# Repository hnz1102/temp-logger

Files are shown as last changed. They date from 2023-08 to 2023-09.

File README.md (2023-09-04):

<div align="center">
  <h1><code>Temperature Logger for K-Type Thermocouple</code></h1>
  <p>
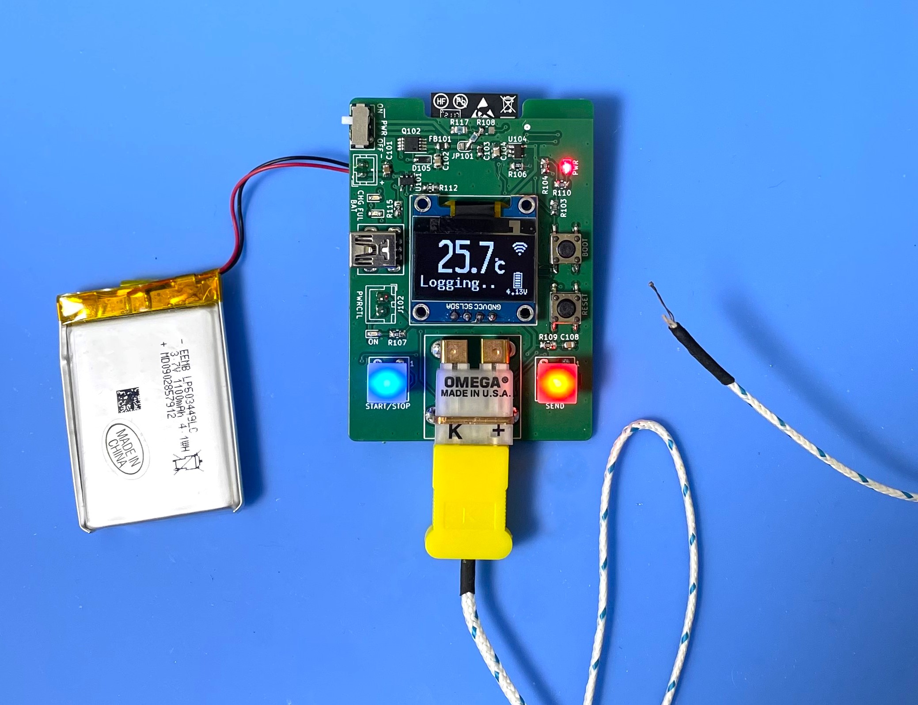
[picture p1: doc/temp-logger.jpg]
    
  </p>
</div>

# TempLogger - Temperature Logger for K-Type Thermocouple

This board provides a logging function that gets data on temperature from a K-type thermocouple.

# Feature

**Microcontroller on board** - No need for a PC when you are measuring a temperature.

**Transfer Temperature data via WiFi** - This Logger can transfer temperature data to Linux PC via WiFi network and you can see the dashboard graph in influxDB.

**Battery Powered** - Using LiPo battery. It can run for 48 hours.

# How to use the TempLogger
Put on the thermocouple where you want to measure the temperature.  

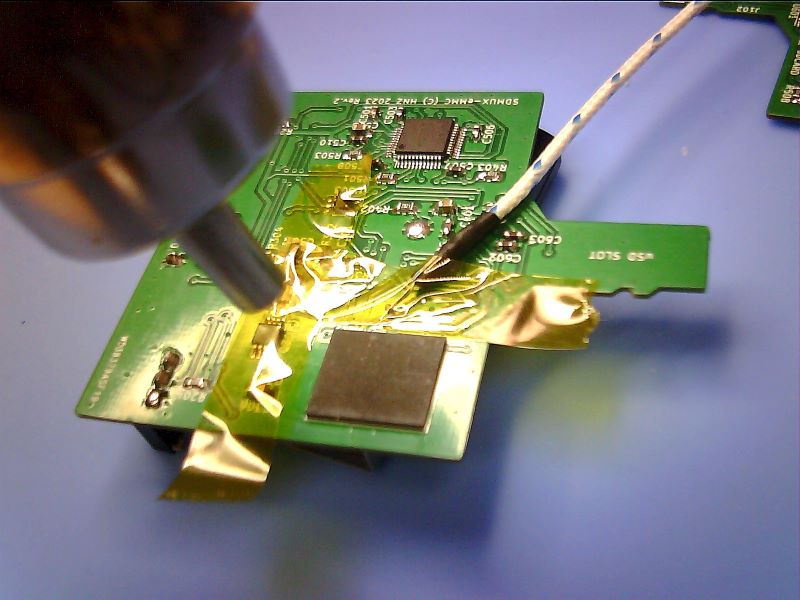
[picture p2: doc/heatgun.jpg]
termocuple


Push the START/STOP button, then TempLogger starts to log the temperature. And if you want to send data on temperature, push the SEND button. During the measurement, TempLogger can send the data to a PC. 

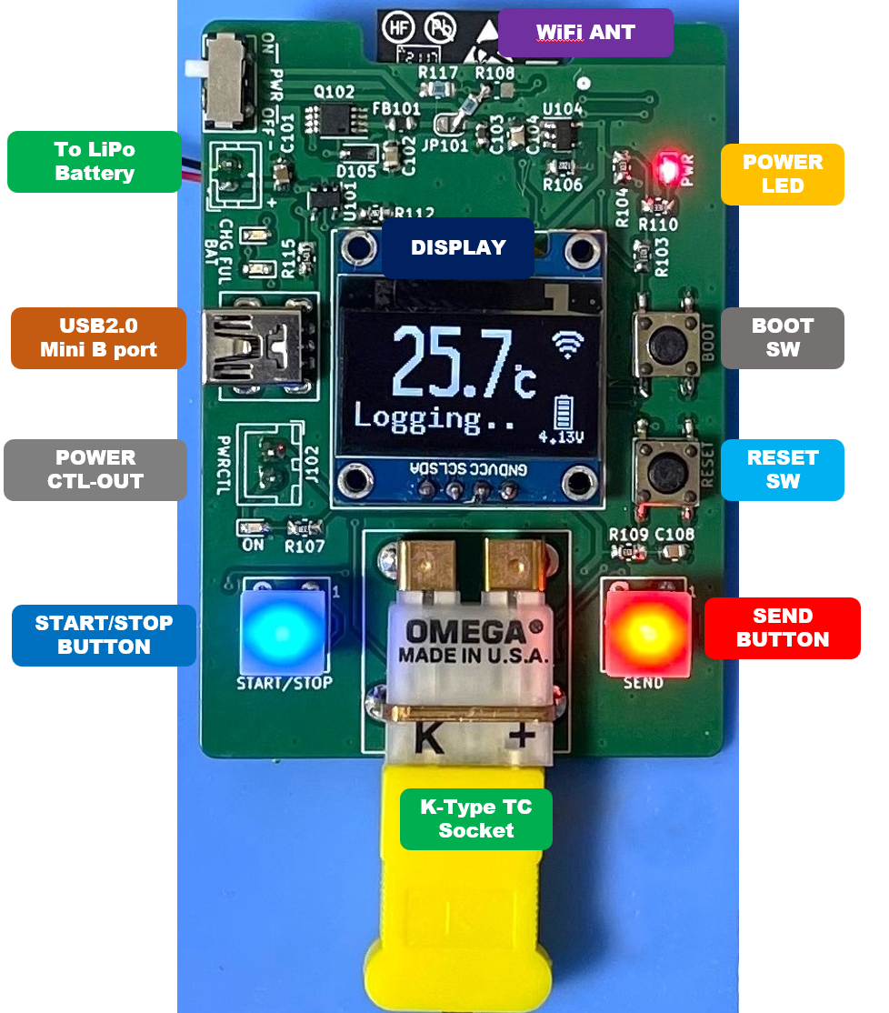
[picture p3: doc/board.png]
board


A display can show you the current temperature, battery voltage, and WiFi connection status.

If WiFi could not connect to WiFi Access Point, the WiFi mark won't be shown on the display.

You can see the realtime data using Dashboard by [InfluxDB](https://www.influxdata.com/influxdb/).

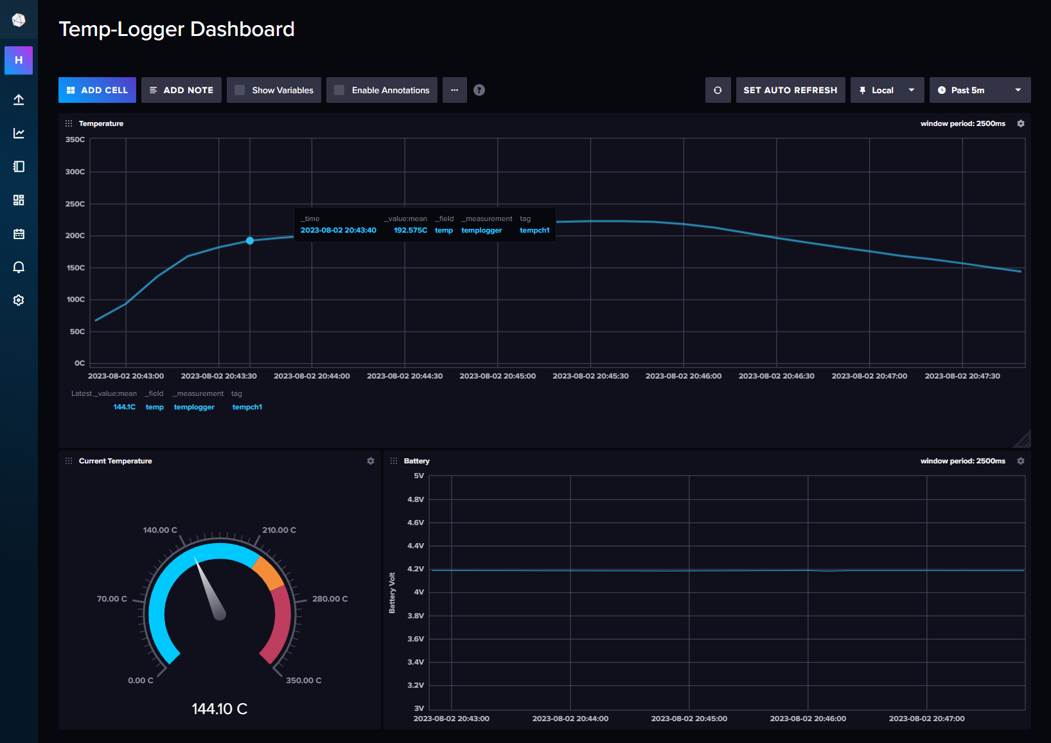
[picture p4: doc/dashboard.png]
dashboard


After the measure, to stop logging, push the START/STOP button again.

To charge a battery, just connect to a USB mini-B port from the bus-powered USB port. During the charge, the CHG LED is RED ON. After the charging is full, the FUL LED is GREEN ON. And the charging will be stopped automatically. But, 

DO NOT CONTINUE THE CHARGE IF THE BATTERY IS FULL FOR A LONG TIME. 

# Case

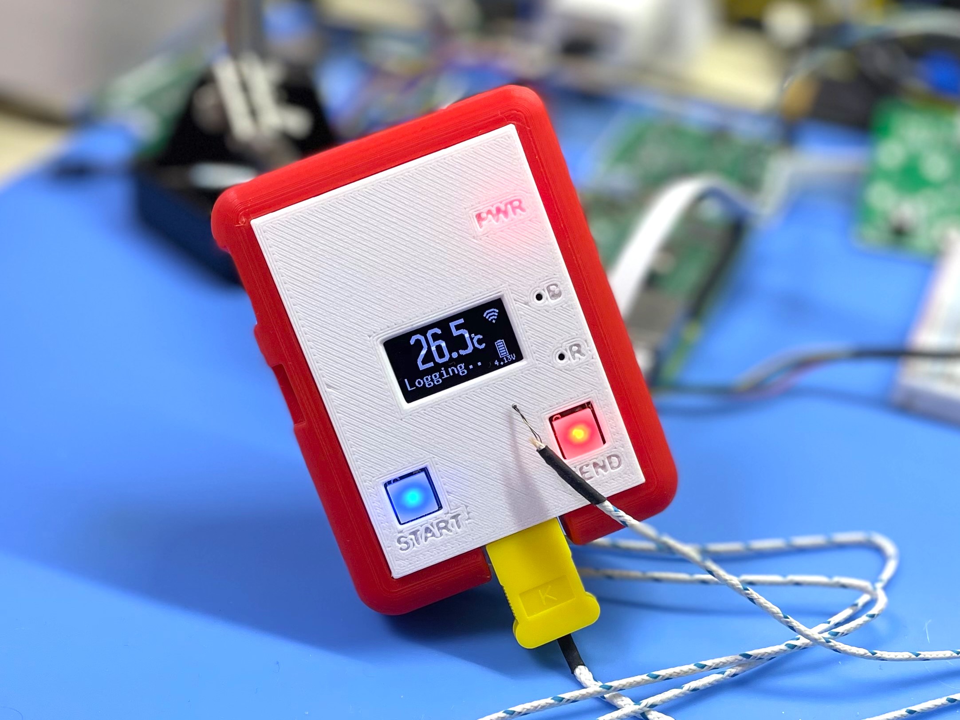
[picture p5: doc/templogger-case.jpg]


There are data for 3D printer in `hardware/*.stl`.

# How to build code

Using Ubuntu 22.04.02 LTS

1. Install Rust Compiler
```bash
$ sudo apt -y install git python3 python3-pip gcc build-essential curl pkg-config libudev-dev libtinfo5 clang libclang-dev llvm-dev udev
$ curl --proto '=https' --tlsv1.2 -sSf https://sh.rustup.rs | sh
select No.1
$ source "$HOME/.cargo/env"
```

2. Install toolchain for ESP32-C3
```bash
$ cargo install ldproxy
$ cargo install espup
$ rustup toolchain install nightly --component rust-src
$ rustup target add riscv32imc-unknown-none-elf
$ cargo install cargo-espflash
```

3. Add UDEV rules
```bash
$ sudo sh -c 'echo "SUBSYSTEMS==\"usb\", ATTRS{idVendor}==\"303a\", ATTRS{idProduct}==\"1001\", MODE=\"0666\"" > /etc/udev/rules.d/99-esp32.rules'
$ sudo udevadm control --reload-rules
$ sudo udevadm trigger
```

4. Download Temp-Logger code
```bash
$ git clone https://github.com/hnz1102/temp-logger.git
$ cd temp-logger/src/temp-logger
``` 
5. Setting WiFi SSID, Password, and InfluxDB server IP address.
```bash
src\temp-logger\cfg.toml

[templogger]
wifi_ssid = "<your-AP-ssid>"     # Set your AP ssid.
wifi_psk = "<your-AP-Password>"  # Set password for ssid
http_server = "<PC address>:3000" # Set IP address and port. port should be 3000.
```

6. Connecting the board and Set device and set toolchain.
```bash
Connecting the Temp-Logger by USB to this build code PC. Then, 
$ cargo espflash board-info
select /dev/ttyACM0
Chip type:         esp32c3 (revision v0.4)
Crystal frequency: 40MHz
Flash size:        4MB
Features:          WiFi, BLE
MAC address:       xx:xx:xx:xx:xx:xx

$ rustup component add rust-src --toolchain nightly-2023-06-10-x86_64-unknown-linux-gnu
```

7. Build code and writing flash
```bash
$ cargo espflash flash --release --monitor
App/part. size:    950,864/3,145,728 bytes, 30.23%
[00:00:00] [========================================]      12/12      0x0                                                                       
[00:00:00] [========================================]       1/1       0x8000                                                                    
[00:00:11] [========================================]     535/535     0x10000                                                                   [2023-08-03T13:05:12Z INFO ] Flashing has completed!

And automaticaly boot!
```

# How to Install the influxDB and Agent

1. Download [influxDB](https://docs.influxdata.com/influxdb/v2.7/install/?t=Linux) and Install.
```bash
$ wget https://dl.influxdata.com/influxdb/releases/influxdb2-2.7.0-amd64.deb
$ sudo dpkg -i influxdb2-2.7.0-amd64.deb
$ sudo service influxdb start
```

2. Configure the influxDB

```
Connect to the 'http://<influxDB installed PC Address>:8086'
```

Click `GET STARTED` and set `Username`, `Password`, `Initial Organization Name`, and `Initial Bucket Name`
|Term|Value|
|---|---|
|Username|Set login username as influxDB administrator web console|
|Password|Set login password as influxDB administrator web console|
|Initial Organization Name| Organization Name ex. ORG|
|Initail Bucket Name| LOGGER |

After set them, click `CONTINUE`.

3. Copy the operator API token.

You can see the operator API token on the browser. YOU WON'T BE ABLE TO SEE IT AGAIN!

After copy the token, click `CONFIGURE LATER`.

4. Import the Dashboard Template.

Click the `Dashboard` icon, and select `Import Dashboard` from the `CREATE DASHBOARD` menu.

Drop the `src/server/temp-logger_dashboard.json` file to `Drop a file here`, then click `IMPORT JSON AS DASHBOARD`.

You can see the `Temp-Logger Dashboard` pannel on the Dashboards page.

Click this panel, and You can see the Temp-Logger Dashboard.

If you want to customize the dashboard design, click configure mark. You can change the graph design.

5. Install the Agent.

Temp-Logger can't directly send data to influxDB API since ESP32-C3 has not TLS software stack. This agent program is responsible for changing HTTP communication from Temp-Logger to HTTPS communication and passing data to the InfluxDB API. This agent is purpose only for a local network because it has no security.

Before install you have to change parameters in main.js.

src/server/main.js
```javascript
const token = "<influxDB API Access Token>"
const url = 'http://<influxDB installed IP address>:8086'
let org = `<YOUR ORGANIZATION NAME: it has to be same the Initial Organization Name>`
let bucket = `LOGGER`
```

Install the agent program.

```bash
$ cd src/server/
$ ./install.sh
```
If it is `Active: active`` as shown below, it has started normally.
```
● influxdb-agent.service - InfluxDB Agent
     Loaded: loaded (/lib/systemd/system/influxdb-agent.service; enabled; vendor preset: enabled)
     Active: active (running) since Sat 2023-08-05 02:24:18 UTC; 15ms ago
```

6. Start Temp-Logger Logging and Send Data.

Push the START/STOP button, and push SEND button. Logging data will be sent to the influxDB. You can see the data on the dashboard.

# Add Battery Monitor

A small modification was made to monitor the battery voltage.

I already fixed new PCB gerber data.

## LICENSE
This source code is licensed under MIT. Other Hardware Schematic documents are licensed under CC-BY-SA V4.0.

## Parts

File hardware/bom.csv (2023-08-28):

Reference | Value | Footprint | akizuki | digikey | storeURL | Qty
C101 | 4.7uF | Capacitor_SMD:C_0805_2012Metric_Pad1.18x1.45mm_HandSolder |  | 311-1455-1-ND | https://www.digikey.com/en/products/detail/yageo/CC0603KRX5R6BB475/2833620 | 1
C102, C108 | 1uF | Capacitor_SMD:C_0805_2012Metric |  | 13-CC0603KPX7R7BB105CT-ND | https://www.digikey.com/en/products/detail/yageo/CC0603KPX7R7BB105/11491211 | 2
C103, C106, C111 | 0.1uF | Capacitor_SMD:C_0603_1608Metric_Pad1.08x0.95mm_HandSolder |  | 311-1824-1-ND | https://www.digikey.com/en/products/detail/yageo/CC0603MRX7R7BB104/5195231 | 3
C104, C107 | 10uF | Capacitor_SMD:C_0805_2012Metric_Pad1.18x1.45mm_HandSolder |  | 311-3494-1-ND | https://www.digikey.com/en/products/detail/yageo/CC0603MRX5R8BB106/7164378 | 2
C105 | 0.1uF | Capacitor_SMD:C_0603_1608Metric |  | 311-1824-1-ND | https://www.digikey.com/en/products/detail/yageo/CC0603MRX7R7BB104/5195231 | 1
C109, C110 | 16pF | Capacitor_SMD:C_0603_1608Metric_Pad1.08x0.95mm_HandSolder |  | 311-1751-1-ND | https://www.digikey.com/en/products/detail/yageo/CC0603JRNPO0BN160/5195160 | 2
D101-D103 | LED RED SML-E12V8WT86 | tbctl:LED_0603_1608Metric_Pad1.05x0.95mm_HandSolder |  | 511-1587-1-ND | https://www.digikey.com/en/products/detail/rohm-semiconductor/SML-E12V8WT86/1641806 | 3
D104 | LED GREEN SML-E12P8WT86 | tbctl:LED_0603_1608Metric_Pad1.05x0.95mm_HandSolder |  | 511-1585-1-ND | https://www.digikey.com/en/products/detail/rohm-semiconductor/SML-E12P8WT86/1641804 | 1
D105 | NSR0340HT1G | Diode_SMD:D_SOD-323_HandSoldering |  | NSR0340HT1GOSCT-ND | https://www.digikey.com/en/products/detail/onsemi/NSR0340HT1G/1981491 | 1
FB101 | BK2125HS601-T | tbctl:L_0603_1608Metric_Pad1.05x0.95mm_HandSolder |  | 240-2399-1-ND | https://www.digikey.com/en/products/detail/laird-signal-integrity-products/HZ0805E601R-10/806759 | 1
J101 | Conn_K_TERM_XH_2P | tbctl:PCC-SMP_D | P-14972 | 1568-1306-ND | https://www.digikey.com/en/products/detail/sparkfun-electronics/PRT-13612/5762456 | 1
J102 | Conn_01x02 | Connector_JST:JST_XH_B2B-XH-A_1x02_P2.50mm_Vertical | C-12247 | 455-2247-ND | https://www.digikey.com/en/products/detail/jst-sales-america-inc/B2B-XH-A-LF-SN/1651045 | 1
J103 | USB_B_Mini | tbctl:usb mini B connector c2235 dim 2 | C-02235 |  | https://akizukidenshi.com/catalog/g/gC-02235/ | 1
J104 | LiPo BATTERY Socket | Connector_JST:JST_PH_B2B-PH-K_1x02_P2.00mm_Vertical | C-12802 | 455-1704-ND | https://www.digikey.com/en/products/detail/jst-sales-america-inc/B2B-PH-K-S/926611 | 1
JP101 | SolderJumper_2_Open | Jumper:SolderJumper-2_P1.3mm_Open_RoundedPad1.0x1.5mm |  |  |  | 1
Q101 | 2N7002K | Package_TO_SOT_SMD:SOT-23 |  | 2N7002K-7DICT-ND | https://www.digikey.com/en/products/detail/diodes-incorporated/2N7002K-7/1934378 | 1
Q102 | IRF7606TRPBF | Package_SO:MSOP-8_3x3mm_P0.65mm |  | IRF7606TRPBFCT-ND | https://www.digikey.com/en/products/detail/infineon-technologies/IRF7606TRPBF/856652 | 1
R101, R102, R107, R110, R113, R114 | 330 | tbctl:R_0805_2012Metric_Pad1.20x1.40mm_HandSolder |  | 311-330GRCT-ND | https://www.digikey.com/en/products/detail/yageo/RC0603JR-07330RL/726769 | 6
R103, R104, R109, R111, R118 | 10K | tbctl:R_0805_2012Metric_Pad1.20x1.40mm_HandSolder |  | 13-RC0603JR-1010KLCT-ND | https://www.digikey.com/en/products/detail/yageo/RC0603JR-1010KL/13694233 | 5
R105, R108, R117 | 20K 1% | tbctl:R_0805_2012Metric_Pad1.20x1.40mm_HandSolder |  | 13-RC0603FR-1320KLCT-ND | https://www.digikey.com/en/products/detail/yageo/RC0603FR-1320KL/13694225 | 3
R106 | 12K 1% | tbctl:R_0805_2012Metric_Pad1.20x1.40mm_HandSolder |  | 311-12.0KHRCT-ND | https://www.digikey.com/en/products/detail/yageo/RC0603FR-0712KL/726913 | 1
R112 | 2K | tbctl:R_0805_2012Metric_Pad1.20x1.40mm_HandSolder |  | 311-2.0KGRCT-ND | https://www.digikey.com/en/products/detail/yageo/RC0603JR-072KL/726726 | 1
R115 | 100K | tbctl:R_0805_2012Metric_Pad1.20x1.40mm_HandSolder |  | 311-100KGRCT-ND | https://www.digikey.com/en/products/detail/yageo/RC0603JR-07100KL/726698 | 1
SW101 | SW_Push_LED | tbctl:LS601-CU_CAP |  |  | https://akizukidenshi.com/catalog/g/gP-13871/ | 1
SW102 | SW_Push_LED | tbctl:LS601-CU_CAP |  |  | https://akizukidenshi.com/catalog/g/gP-13870/ | 1
SW103 | BOOT TS-06104 | tbctl:TS-06104 | P-15969 |  | https://akizukidenshi.com/catalog/g/gP-15969/ | 1
SW104 | RESET TS-06104 | tbctl:TS-06104 | P-15969 |  | https://akizukidenshi.com/catalog/g/gP-15969/ | 1
SW105 | SLIDE_SW IS-1245T-G | tbctl:SLIDE_SW_IS1235-G | P-15368 |  | https://akizukidenshi.com/catalog/g/gP-15368/ | 1
U101 | MCP73831-2-OT | Package_TO_SOT_SMD:SOT-23-5 | I-13288 | MCP73831T-2ACI/OTCT-ND | https://www.digikey.com/en/products/detail/microchip-technology/MCP73831T-2ACI-OT/964301 | 1
U102 | ESP32-C3-WROOM-02-N4 | tbctl:IC18_ESP32-C3-WROOM-02-N4_EXP | M-17493 | 1965-ESP32-C3-WROOM-02-N4CT-ND | https://www.digikey.com/en/products/detail/espressif-systems/ESP32-C3-WROOM-02-N4/14553031 | 1
U103 | MAX31855KASA | Package_SO:SOIC-8_3.9x4.9mm_P1.27mm | I-14486 | MAX31855KASA+TCT-ND | https://www.digikey.com/en/products/detail/analog-devices-inc-maxim-integrated/MAX31855KASA-T/2591213 | 1
U104 | SPX3819M5-L | Package_TO_SOT_SMD:SOT-23-5 |  | 1016-1871-1-ND | https://www.digikey.com/en/products/detail/maxlinear-inc/SPX3819M5-L-TR/2472388 | 1
U105 | SSD1306_DISPLAY | tbctl:OLED I2C DISPLAY |  |  | https://www.amazon.co.jp/gp/product/B08CTZVVLS/ | 1
Y102 | 32.7680KHz | Crystal:Crystal_SMD_3215-2Pin_3.2x1.5mm |  | 2151-RT3215-32.768-12.5-TRCT-ND | https://www.digikey.com/en/products/detail/raltron-electronics/RT3215-32-768-12-5-TR/10273025 | 1

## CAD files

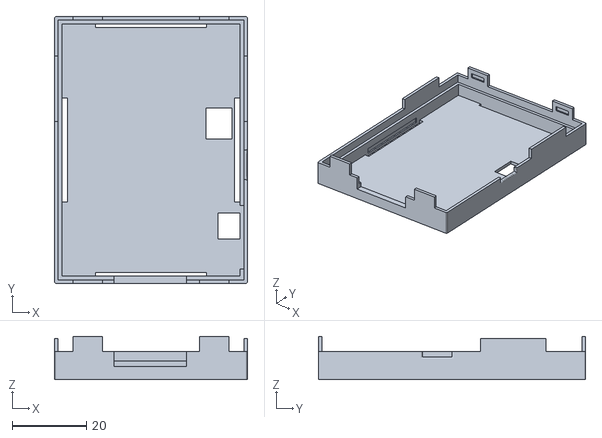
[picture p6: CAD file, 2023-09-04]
hardware/Bottom-v11.stl
52.0 x 72.0 x 11.6

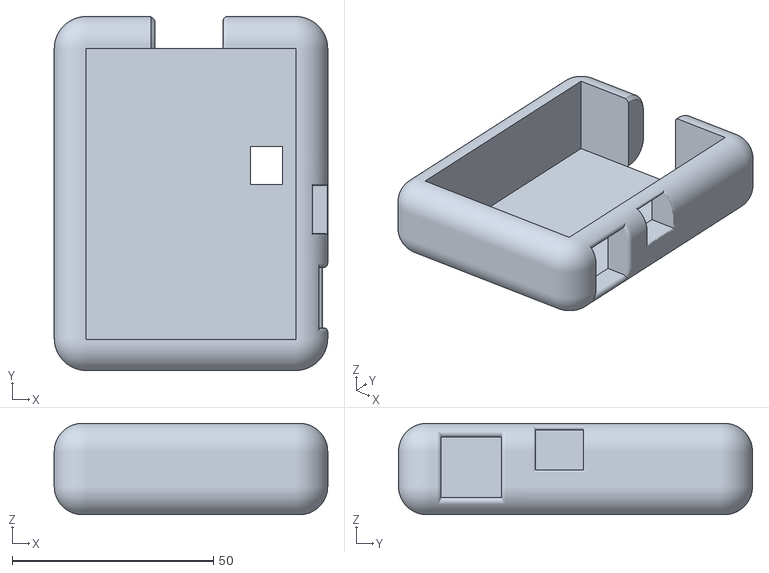
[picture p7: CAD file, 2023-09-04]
hardware/cover-v11.stl
68.0 x 88.0 x 22.7

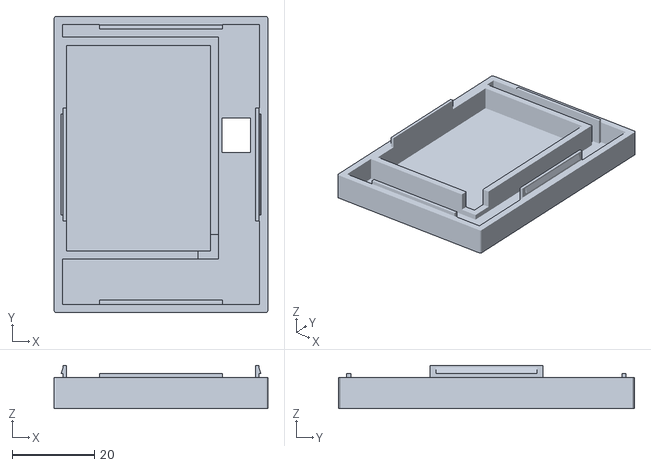
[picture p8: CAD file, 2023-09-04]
hardware/battery-v11.stl
52.0 x 72.0 x 10.5

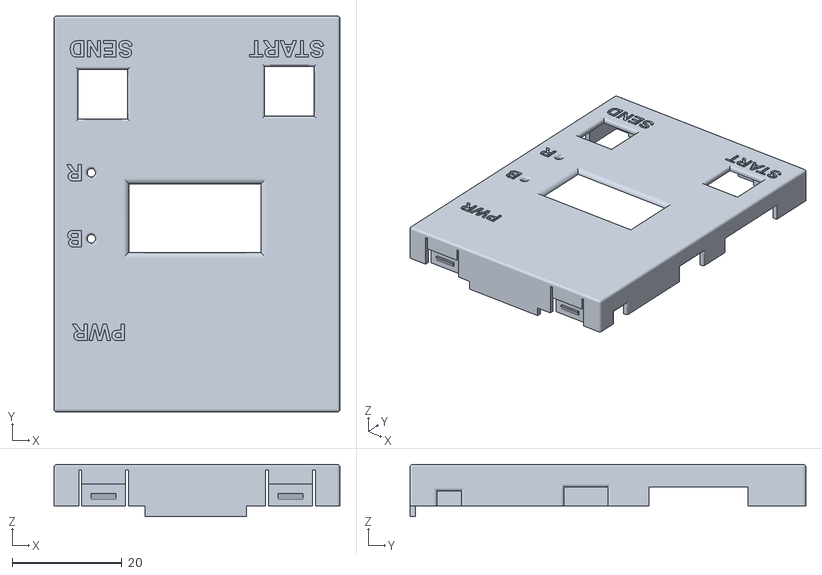
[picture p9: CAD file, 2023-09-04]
hardware/upper-v11.stl
52.0 x 72.0 x 9.50

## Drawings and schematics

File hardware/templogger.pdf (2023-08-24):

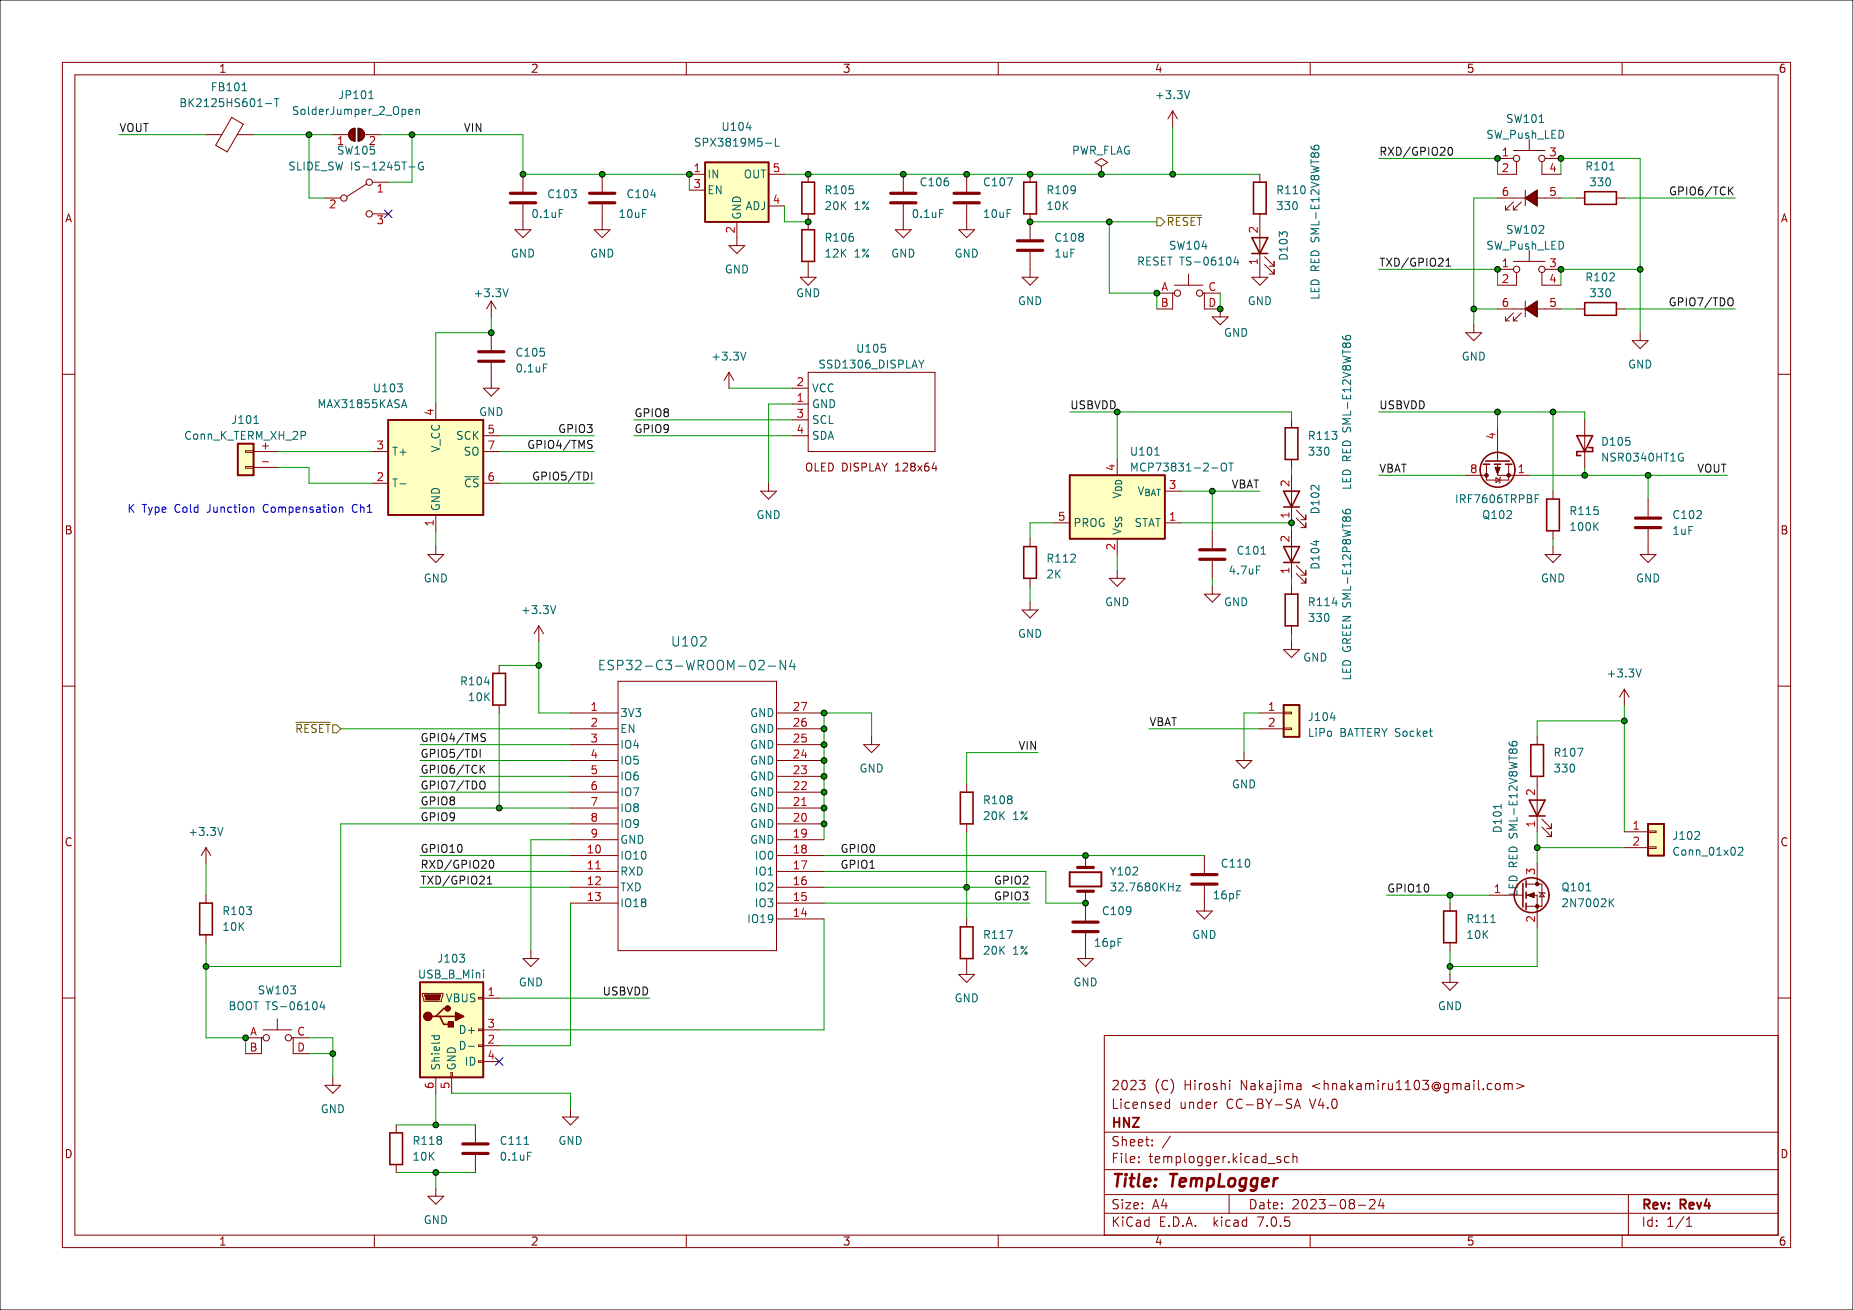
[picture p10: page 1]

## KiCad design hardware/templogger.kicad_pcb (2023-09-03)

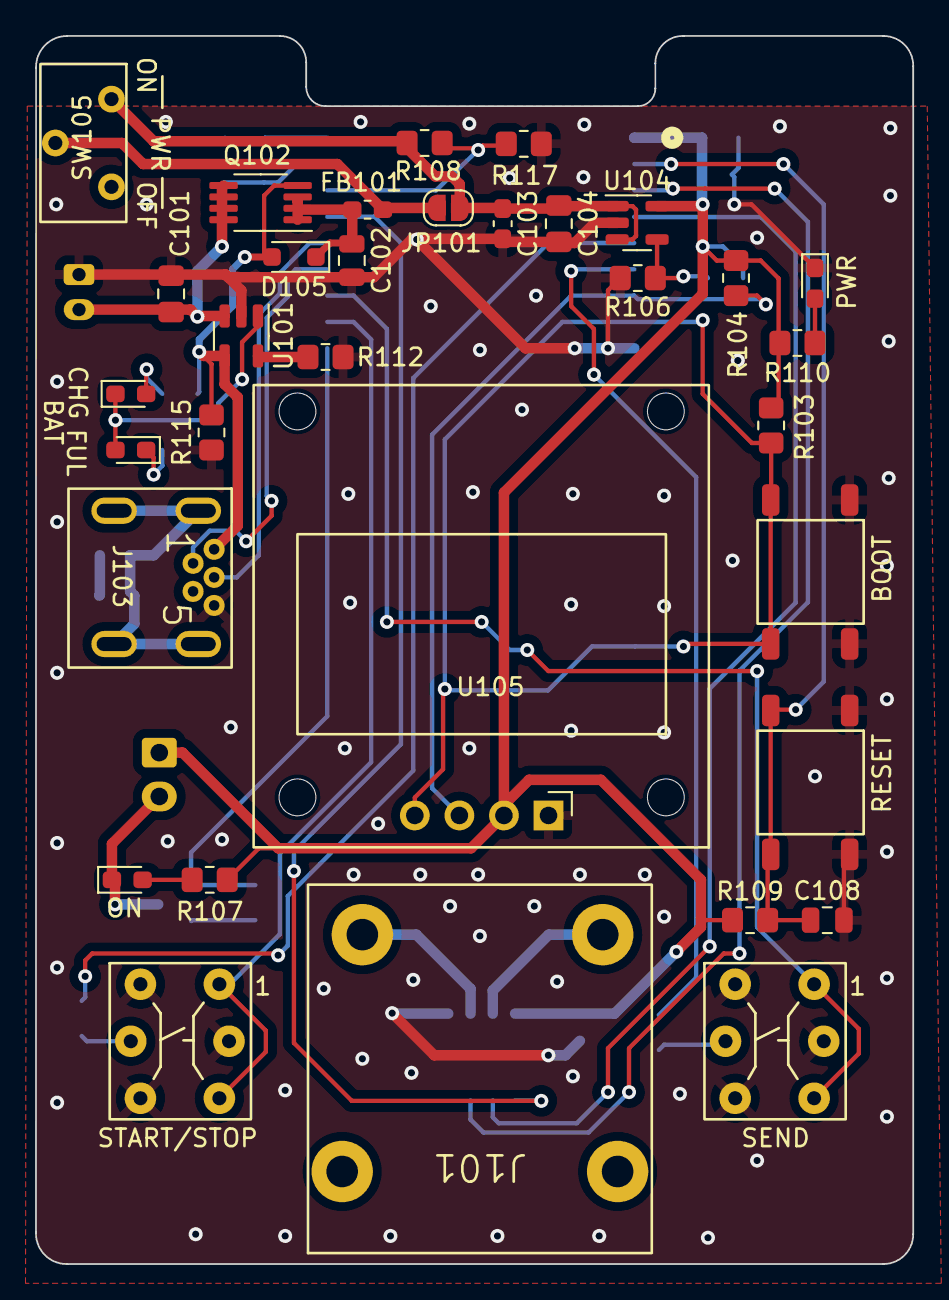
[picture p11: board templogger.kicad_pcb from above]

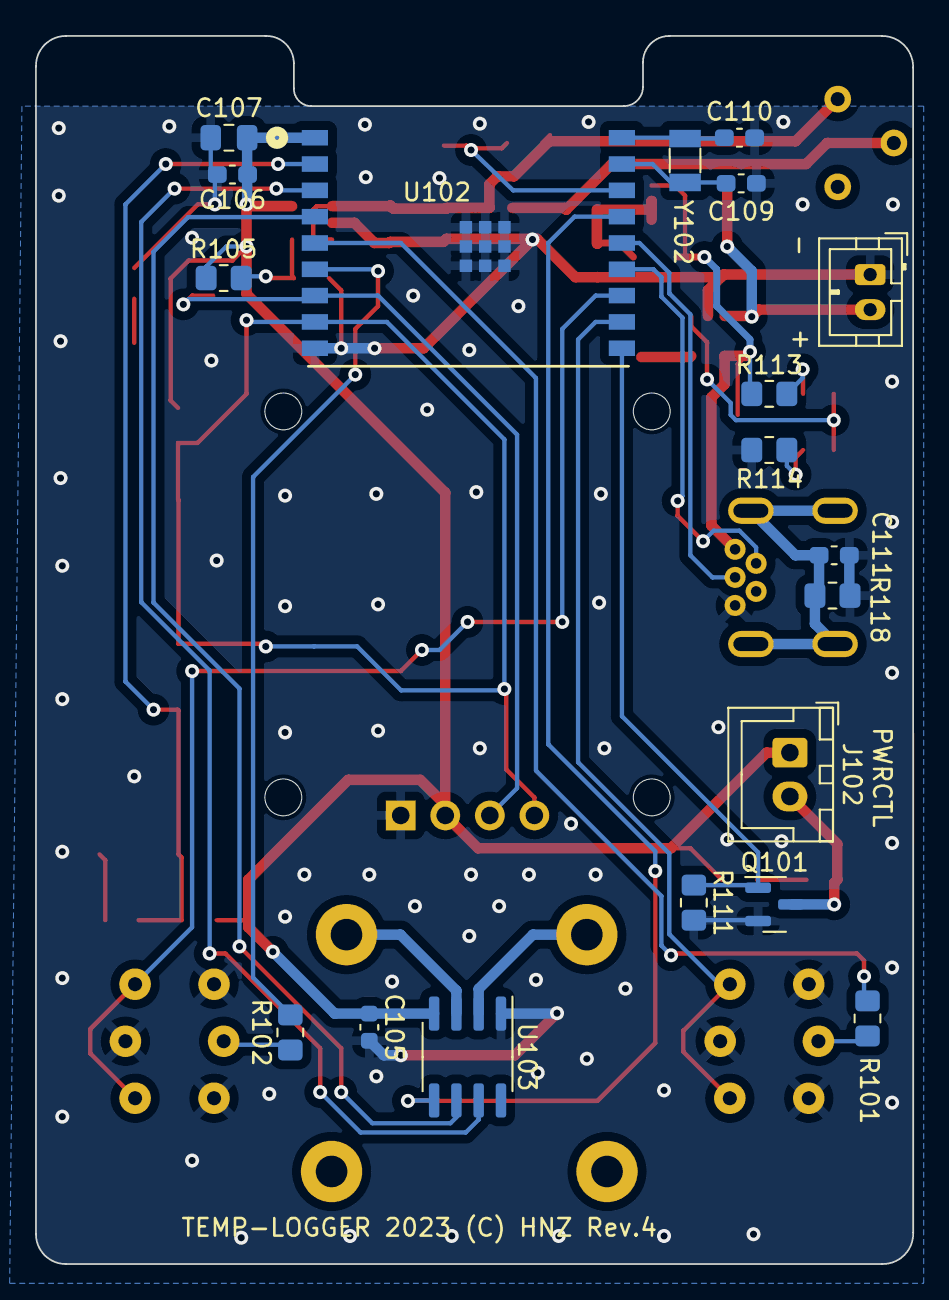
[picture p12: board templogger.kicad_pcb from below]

Board: 2 copper layers, 50.0 x 70.0 mm, 52 parts (19 on the bottom side), 36 nets.

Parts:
C101: 4.7uF; C_0805_2012Metric_Pad1.18x1.45mm_HandSolder
C102, C108: 1uF; C_0805_2012Metric
C103, C106, C111: 0.1uF; C_0603_1608Metric_Pad1.08x0.95mm_HandSolder
C104, C107: 10uF; C_0805_2012Metric_Pad1.18x1.45mm_HandSolder
C105: 0.1uF; C_0603_1608Metric
C109, C110: 16pF; C_0603_1608Metric_Pad1.08x0.95mm_HandSolder
D101, D102, D103: LED RED SML-E12V8WT86; LED_0603_1608Metric_Pad1.05x0.95mm_HandSolder
D104: LED GREEN SML-E12P8WT86; LED_0603_1608Metric_Pad1.05x0.95mm_HandSolder
D105: NSR0340HT1G; D_SOD-323_HandSoldering
FB101: BK2125HS601-T; L_0603_1608Metric_Pad1.05x0.95mm_HandSolder
J101: Conn_K_TERM_XH_2P; PCC-SMP_D
J102: Conn_01x02; JST_XH_B2B-XH-A_1x02_P2.50mm_Vertical
J103: USB_B_Mini; usb mini B connector c2235 dim 2
J104: LiPo BATTERY Socket; JST_PH_B2B-PH-K_1x02_P2.00mm_Vertical
JP101: SolderJumper_2_Open; SolderJumper-2_P1.3mm_Open_RoundedPad1.0x1.5mm
Q101: 2N7002K; SOT-23
Q102: IRF7606TRPBF; MSOP-8_3x3mm_P0.65mm
R101, R102, R107, R110, R113, R114: 330; R_0805_2012Metric_Pad1.20x1.40mm_HandSolder
R103, R104, R109, R111, R118: 10K; R_0805_2012Metric_Pad1.20x1.40mm_HandSolder
R105, R108, R117: 20K 1%; R_0805_2012Metric_Pad1.20x1.40mm_HandSolder
R106: 12K 1%; R_0805_2012Metric_Pad1.20x1.40mm_HandSolder
R112: 2K; R_0805_2012Metric_Pad1.20x1.40mm_HandSolder
R115: 100K; R_0805_2012Metric_Pad1.20x1.40mm_HandSolder
SW101, SW102: SW_Push_LED; LS601-CU_CAP
SW103: BOOT TS-06104; TS-06104
SW104: RESET TS-06104; TS-06104
SW105: SLIDE_SW IS-1245T-G; SLIDE_SW_IS1235-G
U101: MCP73831-2-OT; SOT-23-5
U102: ESP32-C3-WROOM-02-N4; IC18_ESP32-C3-WROOM-02-N4_EXP
U103: MAX31855KASA; SOIC-8_3.9x4.9mm_P1.27mm
U104: SPX3819M5-L; SOT-23-5
U105: SSD1306_DISPLAY; OLED I2C DISPLAY
Y102: 32.7680KHz; Crystal_SMD_3215-2Pin_3.2x1.5mm

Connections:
+3.3V: C105.1, C106.1, C107.1, J102.1, R103.1, R104.1, R105.1, R107.1, R109.1, R110.1, U102.1 (3V3), U103.4 (V_CC), U104.5 (OUT), U105.2 (VCC)
/GPIO0: C110.1, U102.18 (IO0), Y102.2
/GPIO1: C109.1, U102.17 (IO1), Y102.1
/GPIO2: R108.2, R117.1, U102.16 (IO2)
/GPIO3: U102.15 (IO3), U103.5 (SCK)
/GPIO4/TMS: U102.3 (IO4), U103.7 (SO)
/GPIO5/TDI: U102.4 (IO5), U103.6 (~CS)
/GPIO6/TCK: R101.2, U102.5 (IO6)
/GPIO7/TDO: R102.2, U102.6 (IO7)
/GPIO8: R104.2, U102.7 (IO8), U105.3 (SCL)
/GPIO9: R103.2, SW103.A, SW103.B, U102.8 (IO9), U105.4 (SDA)
/GPIO10: Q101.1 (G), R111.1, U102.10 (IO10)
/RXD/GPIO20: SW101.1, SW101.2, U102.11 (RXD)
/TXD/GPIO21: SW102.1, SW102.2, U102.12 (TXD)
/USBVDD: D105.2 (A), J103.1 (VBUS), Q102.4 (G), R113.1, R115.1, U101.4 (V_{DD})
/VBAT: C101.1, J104.2, Q102.5 (D), Q102.6 (D), Q102.7 (D), Q102.8 (D), U101.3 (V_{BAT})
/VIN: C103.1, C104.1, JP101.2 (B), R108.1, SW105.1 (A), U104.1 (IN), U104.3 (EN)
/VOUT: C102.1, D105.1 (K), FB101.1, Q102.1 (S), Q102.2 (S), Q102.3 (S)
/~RESET: C108.1, R109.2, SW104.A, SW104.B, U102.2 (EN)
GND: C101.2, C102.2, C103.2, C104.2, C105.2, C106.2, C107.2, C108.2, C109.2, C110.2, C111.2, D103.1 (K), J103.5 (GND), J104.1, Q101.2 (S), R106.2, R111.2, R112.2, R114.2, R115.2, R117.2, R118.2, SW101.3, SW101.4, SW101.6 (K), SW102.3, SW102.4, SW102.6 (K), SW103.C, SW103.D, SW104.C, SW104.D, U101.2 (V_{SS}), U102.9 (GND), U102.19 (GND), U102.20 (GND), U102.21 (GND), U102.22 (GND), U102.23 (GND), U102.24 (GND), U102.25 (GND), U102.26 (GND), U102.27 (GND), U103.1 (GND), U104.2 (GND), U105.1 (GND)
unnamed: D101.2 (A), R107.2
unnamed: D101.1 (K), J102.2, Q101.3 (D)
unnamed: D102.2 (A), R113.2
unnamed: D102.1 (K), D104.2 (A), U101.1 (STAT)
unnamed: D103.2 (A), R110.2
unnamed: D104.1 (K), R114.1
unnamed: J103.3 (D+), U102.14 (IO19)
unnamed: J103.2 (D-), U102.13 (IO18)
unnamed: C111.1, J103.6 (Shield), R118.1
unnamed: FB101.2, JP101.1 (A), SW105.2 (B)
unnamed: R101.1, SW101.5 (A)
unnamed: R102.1, SW102.5 (A)
unnamed: R112.1, U101.5 (PROG)
unnamed: J101.+, U103.3 (T+)
unnamed: J101.-, U103.2 (T-)
unnamed: R105.2, R106.1, U104.4 (ADJ)

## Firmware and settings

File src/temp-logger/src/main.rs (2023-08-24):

use std::{thread, time::Duration};
use esp_idf_hal::{gpio::*, prelude::*, spi, i2c};
use esp_idf_hal::peripherals::Peripherals;
use esp_idf_hal::ledc::{config::TimerConfig, LedcDriver, LedcTimerDriver};
use embedded_hal::spi::MODE_0;
use log::*;
use std::time::SystemTime;
use esp_idf_hal::adc::config::Config as AdcConfig;
use esp_idf_hal::adc::AdcChannelDriver;
use esp_idf_hal::adc::AdcDriver;
use esp_idf_hal::adc::Atten11dB;

mod pushswitch;
mod displayctl;
mod templogs;
mod wifi;
mod transfer;

use pushswitch::PushSwitch;
use displayctl::{DisplayPanel, LoggingStatus, WifiStatus};
use templogs::{TempRecord, TempLog};
use transfer::Transfer;

#[toml_cfg::toml_config]
pub struct Config {
    #[default("")]
    wifi_ssid: &'static str,
    #[default("")]
    wifi_psk: &'static str,
    #[default("")]
    http_server: &'static str,
}

struct Temperature {
    _ta: f32,
    tr: f32,
    msg: String,
}

fn main() -> anyhow::Result<()> {
    esp_idf_sys::link_patches();
    esp_idf_svc::log::EspLogger::initialize_default();

    // Peripherals Initialize
    let peripherals = Peripherals::take().unwrap();
    
    // PWM
    let timer_driver = LedcTimerDriver::new(peripherals.ledc.timer0, &TimerConfig::default().frequency(50.Hz().into())).unwrap();
    let mut pwm_driver = LedcDriver::new(peripherals.ledc.channel0, timer_driver, peripherals.pins.gpio10).unwrap();
    pwm_driver.set_duty(0).expect("Set duty failure");
    // SPI Temperature
    let spi = peripherals.spi2;
    let sclk = peripherals.pins.gpio3;
    let sdi  = peripherals.pins.gpio4;
    let sdo_not_used = peripherals.pins.gpio1;
    let cs1 = peripherals.pins.gpio5;
    let spi_config = spi::SpiConfig::new().baudrate(1.MHz().into()).data_mode(MODE_0);
    let spi_driver = spi::SpiDriver::new(
        spi,
        sclk,
        sdo_not_used,
        Some(sdi),
        spi::Dma::Disabled,
    ).unwrap();
    
    let spi_shared_device = spi::SpiSharedDeviceDriver::new(spi_driver, &spi_config).unwrap();
    let mut spi1 = spi::SpiSoftCsDeviceDriver::new(&spi_shared_device, cs1, esp_idf_hal::gpio::Level::High).unwrap();

    // Display
    let i2c = peripherals.i2c0;
    let scl = peripherals.pins.gpio8;
    let sda = peripherals.pins.gpio9;
    let config = i2c::I2cConfig::new().baudrate(1.MHz().into());
    let i2c = i2c::I2cDriver::new(i2c, sda, scl, &config)?;
    let mut dp = DisplayPanel::new();
    dp.start(i2c);

    // PushSW
    let startstop_pin   = peripherals.pins.gpio20;
    let send_pin        = peripherals.pins.gpio21;
    let startstop_sig   = Box::new(PinDriver::input(startstop_pin)?);
    let send_sig        = Box::new(PinDriver::input(send_pin)?);
    let mut psw         = PushSwitch::new();
    psw.start(startstop_sig, send_sig);
    let mut startstop_led   = PinDriver::input_output(peripherals.pins.gpio6)?;
    let mut sending_led     = PinDriver::input_output(peripherals.pins.gpio7)?;
    startstop_led.set_low()?;
    sending_led.set_low()?;

    // Temperature Logs
    let mut tlogs = TempRecord::new();

    // WiFi
    let wifi_enable : bool;
    let wifi = wifi::wifi_connect(peripherals.modem, CONFIG.wifi_ssid, CONFIG.wifi_psk);
    match wifi {
        Ok(_) => { wifi_enable = true; },
        Err(e) => { info!("{:?}", e); wifi_enable = false }
    }
    let mut txd =  Transfer::new(CONFIG.http_server.to_string());
    txd.start()?;
    
    // ADC
    let mut adc = AdcDriver::new(peripherals.adc1, &AdcConfig::new().calibration(true))?;
    let mut adc_pin: esp_idf_hal::adc::AdcChannelDriver<'_, Gpio2, Atten11dB<_>> =
        AdcChannelDriver::new(peripherals.pins.gpio2)?;

    // loop
    let mut count : u32 = 0;
    let mut logging_start = false;
    let mut sending_start = false;
    let mut now = SystemTime::now();
    loop {
        thread::sleep(Duration::from_millis(100));
        let start_stop_btn = psw.get_gpio_state(20);
        let sending_btn = psw.get_gpio_state(21);
        if start_stop_btn == true {
            if logging_start == true {
                // to Stop
                logging_start = false;
                dp.set_current_status(LoggingStatus::Stop);
                tlogs.dump();
                tlogs.clear();
                startstop_led.set_low()?;                
            }
            else {
                // to Start
                logging_start = true;
                info!("Logging Start..");
                now = SystemTime::now();
                dp.set_current_status(LoggingStatus::Start);
                startstop_led.set_high()?;
            }
        }
        if sending_btn == true {
            if sending_start == true {
                // Stop Sending
                sending_start = false;
                sending_led.set_low()?;
                if logging_start == true {
                    dp.set_current_status(LoggingStatus::Start);
                }
                else {
                    dp.set_current_status(LoggingStatus::Stop);
                }
            }
            else {
                // Start Sending Data
                sending_start = true;
                sending_led.set_high()?;
            }
        }
        if wifi_enable == false{
            dp.set_wifi_status(WifiStatus::Disconnected);
        }
        else {
            dp.set_wifi_status(WifiStatus::Connected);
        }
        count += 1;
        if count % 10 != 0 {
            continue;
        }
        // Read Power Voltage mV
       let pvol =  adc.read(&mut adc_pin).unwrap() as f32 * 2.0 / 1000.0;
       dp.set_power_voltage(pvol);

        // Read Temperature
        let mut temp = [0u8; 4];
        let mut data = TempLog::default();
        data.vol = pvol;
        match spi1.read(&mut temp) {
            Ok(_v) => {
                let temp1 = get_temp(&temp);
                match temp1 {
                    Ok(v) => {
                        dp.set_panel_temp(v.tr);
                        data.pt = v.tr;
                    }
                    Err(e) => {
                        dp.set_err_message(1, e.msg);
                        data.pt = -99.99;
                    }
                }        
            },
            Err(e) => { info!("{:?}", e); }
        }
        data.clock = now.elapsed().unwrap().as_millis() as u32;
        if logging_start {
            tlogs.record(data);
        }
        if wifi_enable == true && sending_start == true {
            let logs = tlogs.get_all_data();
            let txcount = txd.set_transfer_data(logs);
            if txcount > 0 {
                tlogs.remove_data(txcount);
            }
        }
    }
}

fn get_temp(temp: & [u8; 4]) -> Result<Temperature, Temperature>
{
    let msg;
    match temp[3] & 0x7 {
        0x01 => { msg = "OC ERROR"  },
        0x02 => { msg = "SCG ERROR" },
        0x04 => { msg = "SCV ERROR" },
        _ => {
            let tempval : i32 = (((temp[0] as i8) as i32) << 6) | ((temp[1] >> 2) as i32);
            let intempval : i32 = (((temp[2] as i8) as i32) << 4) | ((temp[3] >> 4) as i32);
            let ta = (intempval as f32) * 0.0625;
            let tr = (tempval as f32) * 0.25;
            return Ok(Temperature { _ta: ta, tr: tr, msg: "OK".to_string() });
        }
    }
    Err(Temperature { _ta: 0.0, tr: 0.0, msg: msg.to_string() })
}

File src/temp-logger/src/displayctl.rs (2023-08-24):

use log::*;
use std::{thread, time::Duration, sync::Arc, sync::Mutex};
use esp_idf_hal::i2c;
use ssd1306::{I2CDisplayInterface, prelude::*, Ssd1306};
use embedded_graphics::{
    mono_font::{ascii::FONT_10X20, ascii::FONT_5X8, MonoTextStyle},
    image::Image,
    pixelcolor::{BinaryColor},
    text::{Text},
    geometry::Point,
    prelude::*,
};
use tinybmp::Bmp;

pub enum LoggingStatus {
    Start,
    Stop,
}

pub enum WifiStatus {
    Connected,
    Disconnected,
}

type DISPLAYIF<'d> = i2c::I2cDriver<'static>;

struct DisplayText {
    panel_temp: f32,
    panel_msg: String,
    // target_temp: f32,
    target_msg: String,
    setup_temp: String,
    // current_power: u32,
    status: LoggingStatus,
    wifi: WifiStatus,
    // menu: String,
    pvol: String,
    volt: f32,
}

pub struct DisplayPanel {
    txt: Arc<Mutex<DisplayText>>
}

impl DisplayPanel {
    pub fn new() -> DisplayPanel {
        DisplayPanel { txt: Arc::new(Mutex::new(
            DisplayText {panel_temp: 0.0,
                         panel_msg: "".to_string(),
                        //  target_temp: 0.0,
                         target_msg: "".to_string(),
                         setup_temp: "".to_string(),
                        //  current_power: 0,
                         status: LoggingStatus::Stop,
                         wifi: WifiStatus::Disconnected,
                        //  menu: "".to_string(),
                         pvol: "".to_string(),
                         volt: 0.0,
                     })) }
    }

    pub fn start(&mut self, i2c : DISPLAYIF )
    {
        let txt = self.txt.clone();
        let _th = thread::spawn(move || {
            info!("Start Display Thread.");
            let interface = I2CDisplayInterface::new(i2c);        
            let mut display = Ssd1306::new(interface, 
                DisplaySize128x64,
                ssd1306::prelude::DisplayRotation::Rotate180)
                .into_buffered_graphics_mode();        
            display.init().unwrap();
            let style = MonoTextStyle::new(&FONT_10X20, BinaryColor::On);
            let small_style = MonoTextStyle::new(&FONT_5X8, BinaryColor::On);
            display.clear();
            display.flush().unwrap();
            let wifibmp = Bmp::from_slice(include_bytes!("./img/wifirev.bmp")).unwrap();
            let wifi_img: Image<Bmp<BinaryColor>> = Image::new(&wifibmp, Point::new(108,1));

            // Battery BMP
            let bat0 = Bmp::from_slice(include_bytes!("./img/battery-0.bmp")).unwrap();
            let bat0_img: Image<Bmp<BinaryColor>> = Image::new(&bat0, Point::new(110,36));
            let bat20 = Bmp::from_slice(include_bytes!("./img/battery-20.bmp")).unwrap();
            let bat20_img: Image<Bmp<BinaryColor>> = Image::new(&bat20, Point::new(110,36));
            let bat40 = Bmp::from_slice(include_bytes!("./img/battery-40.bmp")).unwrap();
            let bat40_img: Image<Bmp<BinaryColor>> = Image::new(&bat40, Point::new(110,36));
            let bat60 = Bmp::from_slice(include_bytes!("./img/battery-60.bmp")).unwrap();
            let bat60_img: Image<Bmp<BinaryColor>> = Image::new(&bat60, Point::new(110,36));
            let bat80 = Bmp::from_slice(include_bytes!("./img/battery-80.bmp")).unwrap();
            let bat80_img: Image<Bmp<BinaryColor>> = Image::new(&bat80, Point::new(110,36));
            let bat100 = Bmp::from_slice(include_bytes!("./img/battery-100.bmp")).unwrap();
            let bat100_img: Image<Bmp<BinaryColor>> = Image::new(&bat100, Point::new(110,36));
            let usbpwr = Bmp::from_slice(include_bytes!("./img/usb-power.bmp")).unwrap();
            let usbpwr_img: Image<Bmp<BinaryColor>> = Image::new(&usbpwr, Point::new(110,36));

            // Number BMP
            let n0 = Bmp::from_slice(include_bytes!("./img/n0.bmp")).unwrap();
            let n0_img: Image<Bmp<BinaryColor>> = Image::new(&n0, Point::zero());
            let n1 = Bmp::from_slice(include_bytes!("./img/n1.bmp")).unwrap();
            let n1_img: Image<Bmp<BinaryColor>> = Image::new(&n1, Point::zero());
            let n2 = Bmp::from_slice(include_bytes!("./img/n2.bmp")).unwrap();
            let n2_img: Image<Bmp<BinaryColor>> = Image::new(&n2, Point::zero());
            let n3 = Bmp::from_slice(include_bytes!("./img/n3.bmp")).unwrap();
            let n3_img: Image<Bmp<BinaryColor>> = Image::new(&n3, Point::zero());
            let n4 = Bmp::from_slice(include_bytes!("./img/n4.bmp")).unwrap();
            let n4_img: Image<Bmp<BinaryColor>> = Image::new(&n4, Point::zero());
            let n5 = Bmp::from_slice(include_bytes!("./img/n5.bmp")).unwrap();
            let n5_img: Image<Bmp<BinaryColor>> = Image::new(&n5, Point::zero());
            let n6 = Bmp::from_slice(include_bytes!("./img/n6.bmp")).unwrap();
            let n6_img: Image<Bmp<BinaryColor>> = Image::new(&n6, Point::zero());
            let n7 = Bmp::from_slice(include_bytes!("./img/n7.bmp")).unwrap();
            let n7_img: Image<Bmp<BinaryColor>> = Image::new(&n7, Point::zero());
            let n8 = Bmp::from_slice(include_bytes!("./img/n8.bmp")).unwrap();
            let n8_img: Image<Bmp<BinaryColor>> = Image::new(&n8, Point::zero());
            let n9 = Bmp::from_slice(include_bytes!("./img/n9.bmp")).unwrap();
            let n9_img: Image<Bmp<BinaryColor>> = Image::new(&n9, Point::zero());
            let cc = Bmp::from_slice(include_bytes!("./img/c.bmp")).unwrap();
            let cc_img: Image<Bmp<BinaryColor>> = Image::new(&cc, Point::new(88, 0));
            let dot = Bmp::from_slice(include_bytes!("./img/dot.bmp")).unwrap();
            let dot_img: Image<Bmp<BinaryColor>> = Image::new(&dot, Point::new(60, 0));
            let minus = Bmp::from_slice(include_bytes!("./img/minus.bmp")).unwrap();
            let minus_img: Image<Bmp<BinaryColor>> = Image::new(&minus, Point::zero());
            let mut digit_img = n0_img.translate(Point::new(0,0));
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

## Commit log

2023-08-06 Add gerber file and update BOM list
    [bom.csv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]
2023-08-06 remove UTF characters
    [bom.csv]
2023-08-12 Fixed to read max31855 when it's minus temperature
    [displayctl.rs, main.rs]
2023-08-24 Fixed battery socket
    [templogger-B_Cu.gbr, templogger-B_Mask.gbr, templogger-B_Paste.gbr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]
2023-08-24 Add usb power icon
2023-08-28 Add case data for 3d printer
    [Bottom-v10.stl, battery-v10.stl, upper-v10.stl]
2023-08-28 Update bom list
    [bom.csv]
2023-09-03 Fixed a pcb edge line.
    [templogger.kicad_pcb]
2023-09-04 Update case design
    [Bottom-v11.stl, battery-v11.stl, cover-v11.stl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]
2023-09-04 Fixed typo
    [Bottom-v10.stl, battery-v10.stl, upper-v10.stl]
